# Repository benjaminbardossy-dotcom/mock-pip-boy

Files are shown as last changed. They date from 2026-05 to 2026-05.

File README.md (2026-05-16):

# Overview
The wrist boy is a wrist mounted device containing modules which allow it to take in readings such as the outside temperature, humidity, air pressure, air quality, user heart rate / SpO2 of the user. Readings will be displayed onto a 2.42in I2C OLED, which the player can interact with using the buttons attached. Other features include:\
-2 pairs of LED's acting as straight or perpendicular flashlights\
-A laser pointer(toggled through switches)\
-Vl53l0X module which can measure distance\
-A laser pointer for better accuracy when measuring distance\
-A small speaker + mic\
+Many other software features\
For a more indepth look at the features, see [Features](#features)\
**This design is still a WIP, and many other features are planned. See [The Future of The Wrist Boy](#the-future-of-the-wrist-boy)

# Why I Made This
I was inspired to make this after coming across this project: [The Chip-Boy](https://github.com/hungggryvic/Chip-Boy). Seeing this project, I was inspired to make my own with similar modules.

Despite similar ideas, I had envisioned a few changes to the design, including adding more "survival" based modules. I wanted this device to warn the user if there was any potential danger. To implement this, I added an SpO2 module to measure the users heartrate, an AHT20+BMP280 module for temp and air pressure, an MQ135 module for air quality, and a red LED which would flash if there was any potential danger to the user(E.x. low air quality readings from the MQ135, high temp readings from the AHT20+BMP280.).

However, the idea behind the wrist boy was always the same. I wanted a device able to take in readings from the environment around me, anytime, anywhere, with versatile highly modifiable modules which could easily be coded to fit any need. I wanted a device which could connect to wifi if needed, but run completely off grid whenever necessary as long as it has charge.

After taking into consideration what I wanted from this device, I've created the design below:

# The Design(WIP):

## Features
- **Main Functionality**
   - Custom PCB powered by an ESP32 module which serves as the heart of the device as it handles all firmware
   - Responsive user interface, which is displayed on an 2.42 inch OLED screen, and can be interacted with through the attached switches
   - Rechargeable LIPO battery which can be charged through the attached TP4056 module.
   - laser which toggles on for accurate measurement when using the VL53L0X, or can alternatively be toggled through the second switch attached
   - 2 pairs of LED's which function as flashlights for the user, and are toggled through the attached switches
   - Micro SD card reader module which function as extended storage for the ESP32. For this device it stores music data, which can then be played on the attached speaker.
- **Environmental Data Gathering**
   - MAX30102 module to measure the users heatrate
   - MQ135 module to measure general air quality
   - AHT20+BMP280 to measure environmental temperature and air pressure
   - VL53L0X module for accurately measuring distance to the nearest mm
- **Audio**
   - Small speaker to play music or other audio
   - Small microphone which takes in audio and can be used to program a variety of features, such as voice activated commands
   - A piezo buzzer which adds depth to the interface by playing different frequency beeps depending on user input

## The Case
\
I designed a case to mount the PCB to, which could then slip onto the user's wrist. The case features two separate pieces which snap together to ease 3D printing and reduce support generation where possible. The PCB itself mounts to the case through the use of M2 screws. The case features 4 small holes in each corner to place M2 heat inserts into, which then mount the PCB in place by screwing in 4 M2 screws into the 4 corners of the PCB. The case includes a small rectangular hole near the bottom, which the SpO2 module slots into, before the wires are strung through the hollow case and connected to the PCB. This allows proper heart rate readings to be read, as the module is lightly pressed into the user's wrist at constant pressure. The case also includes holes for both the MQ135 and AHT20+BMP280, allowing the sensors to fit into the case and under the PCB.

## The PCB
\
The PCB features a 2 layer design, with a track size of 0.25mm, and an overall sizing of 67x107mm. The microcontroller used was the ESP32. which is soldered directly to the board. The OLED screen is quite large, sitting at 48x70mm, and for this reason it is mounted to female headers, allowing it to sit overtop of the ESP32 and other components. The two pairs of LED's sit off the board, acting as flashlights.
## 3D View:
\

## Wiring Schematic

This wiring schematic is identical to the routing on the PCB, but shown in greater detail.

# Assembling Your Own
If you're interested in creating your own wrist boy, the simplified construction of the wrist boy is as follows:
1. Gather the necessary files(All files / folders referenced can be found at the top of this repo):
   - Download the step files found in folder labeled CAD Models
   - Download the zip file containing the gerber files for the PCB labeled wrist_boy_gerber.zip, found in the folder labeled PCB
2. Gather the Parts
   - See the BOM below and order any parts you don't already have using the links provided
   - Go to JLCPCB and start a new order
   - Drag and drop wrist_boy_gerber.zip into the file uploader
   - Submit the order
   - Upload the step files to a 3D printing application of your choice and print the models OR upload the step files to JLCPCB's 3D printing service and add to your existing PCB order if you don't have access to a 3D printer
3. Assemble
   - Solder components to the board following the rules below and using the schematic as reference
      - make sure to solder a 4 pin female header instead of the screen to the designated OLED pins on the board
      - Do not solder the aht20+bmp280, MQ135, laser pointer, or MAX30102 directly to the board
   - Place the MAX30102 into its designated slot near the bottom of the case, placing the wires through the case
   - Superglue the connecting pieces of the 3D printed case together and let set
   - Place the MQ135 and aht20+bmp280 into their places in the case, securing with M2 screws and nuts
   - Optionally mount the laser pointer to the top of the VL53l0X
   - Use the solder gun to melt the M2 heat inserts into the case in the holes located at each corner of the case
   - Place battery into the case and secure with double sided tape
   - Place the PCB on top of the case in line with the holes
   - Using M2 screws, secure the PCB to the case
4. Firmware
   - Download the code using the provided ino file wristboy_untested.ino
   - Plug the ESP32 in, and connect to whatever device you're using to upload the code
   - Upload the code to the ESP32

## BOM
| Material | Quantity | Cost($CAD) | Link |
| --- | --- | --- | --- |
| M2 Screws | 10 | 0.21 | https://www.amazon.ca/780Pcs-Screws-Metric-Washers-Steel-Black/dp/B0D7QCS5FL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 |
| M2 Nuts | 6 | 0.12 | https://www.amazon.ca/780Pcs-Screws-Metric-Washers-Steel-Black/dp/B0D7QCS5FL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 |
| M2 Heat Inserts | 4 | 0.56 | https://www.amazon.ca/HANGLIFE-Heat-Set-Threaded-Components-Soldering/dp/B0D477R64K?th=1 |
| ESP32 | 1 | 10.99 | https://www.amazon.ca/ELEGOO-ESP-WROOM-32-Development-Bluetooth-Microcontroller/dp/B0D8T7Z1P5?th=1 |
| Mini Step-Up Boost Converter | 1 | 3.66 | https://www.amazon.ca/CANADUINO%C2%AE-DC-DC-Step-Up-Converter-2-5-5V/dp/B09TZSGHYK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 |
| 3.7V 18650A 2000mAh LIPO Battery | 1 | 8.63 | https://www.aliexpress.com/item/1005010527559361.html?spm=a2g0o.order_list.order_list_main.5.46711802fXqOzT |
| 5 Way Switch | 1 | 0.88 | https://www.aliexpress.com/item/4000681560472.html?spm=a2g0o.order_list.order_list_main.44.46711802fXqOzT |
| Mini Laser Pointer | 1 | 0.66 | https://www.aliexpress.com/item/1005009410058180.html?spm=a2g0o.order_list.order_list_main.50.46711802fXqOzT |
| 2.42 inch OLED Display  | 1 | 13.58  | https://www.aliexpress.com/item/4000002579405.html?spm=a2g0o.order_list.order_list_main.61.46711802fXqOzT |
| TP4056 Lithium Battery Charger Module | 1 | 0.47 | https://www.aliexpress.com/item/32930640893.html?spm=a2g0o.order_list.order_list_main.71.46711802fXqOzT |
| VL53L0X Module | 1 | 5.69 | https://www.aliexpress.com/item/1005008798415699.html?spm=a2g0o.order_list.order_list_main.191.49da1802f3M5CC |
| MAX30102 Module | 1 | 3.07 | https://www.aliexpress.com/item/1005007015407514.html?spm=a2g0o.order_list.order_list_main.56.64ef1802V6ZYNr |
| MQ135 Module | 1 | 5.09 | https://www.aliexpress.com/item/1005009467470672.html?spm=a2g0o.order_list.order_list_main.91.46711802fXqOzT |
| AHT20+BMP280 Module | 1 | 4.89 | https://www.aliexpress.com/item/1005005982427374.html?spm=a2g0o.order_list.order_list_main.96.46711802fXqOzT |
| Mini Slide Switch 3pin | 3 | 0.37 | https://www.aliexpress.com/item/1005005633418066.html?spm=a2g0o.order_list.order_list_main.171.46711802fXqOzT |
| Micro Push Button | 2 | 0.10 | https://www.aliexpress.com/item/32815969627.html?spm=a2g0o.order_list.order_list_main.196.46711802fXqOzT |
| Led Diode, 3mm 5mm | 5 | 0.35 | https://www.aliexpress.com/item/1005007214694188.html?spm=a2g0o.order_list.order_list_main.226.46711802fXqOzT |
| Resistors | 10 | 0.06 | https://www.aliexpress.com/item/1005005855324735.html?spm=a2g0o.order_list.order_list_main.241.46711802fXqOzT |
| INMP441 Module | 1 | 5.89 | https://www.aliexpress.com/item/1005011560363321.html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 |
| Micro SD Card Module | 1 | 3.71 | https://www.aliexpress.com/item/1005010519562186.html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 |
| MAX98357A Module | 1 | 3.07  | https://www.aliexpress.com/item/1005007068815767.html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 |
| 8Ohm 1W Speaker | 1 | 4.82 | https://www.aliexpress.com/item/1005011920753806.html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 |
| Piezo Buzzer | 1 | 0.27 | https://www.aliexpress.com/item/1005006260328559.html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 |

# The Future of The Wrist Boy
This design is not final, and I plan on refining the PCB and case alot more in the future. I plan on having a fully integrated circuit with no prebuilt modules, which woiuld save space and allow me to build a full case which encloses the hardware, and I also plan on changing and refining the code as I test the hardware. Another large modification I have planned is the addition of a 5V solar panel to charge the battery, attached to a custom PCB which allows both USB-C charging and solar charging.

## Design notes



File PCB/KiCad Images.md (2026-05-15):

**KiCad schematic as an image:**

\
**KiCad pcb as an image**


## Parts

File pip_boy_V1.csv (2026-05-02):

Reference | Qty | Value | DNP | Exclude from BOM | Exclude from Board | Footprint | Datasheet | "Link"
BZ1 | 1 | Buzzer |  |  |  | custom_footprints:Piezo_buzzer_D10mm | ~ | "https://www.aliexpress.com/item/1005006260328559.html?curPageLogUid=fZmKYKihIY1A"
D1,D2,D3,D4,D5 | 5 | LED |  |  |  | Connector_PinSocket_2.54mm:PinSocket_2x01_P2.54mm_Vertical | ~ | "https://www.aliexpress.com/item/1005007214694188.html"
L1 | 1 | LASER |  |  |  | TestPoint:TestPoint_2Pads_Pitch5.08mm_Drill1.3mm | ~ | "https://www.aliexpress.com/item/1005009410058180.html"
R1,R2,R3,R4,R5,R6 | 6 | 10 |  |  |  | custom_footprints:Resistor_THT_L5.00mm_D1.0mm | ~ | "https://www.aliexpress.com/item/1005005855324735.html"
R7,R8 | 2 | 100K |  |  |  | custom_footprints:Resistor_THT_L5.00mm_D1.0mm | ~ | "https://www.aliexpress.com/item/1005005855324735.html"
R9 | 1 | 180 |  |  |  | custom_footprints:Resistor_THT_L5.00mm_D1.0mm | ~ | "https://www.aliexpress.com/item/1005005855324735.html"
S1 | 1 | Speaker |  |  |  | TestPoint:TestPoint_2Pads_Pitch5.08mm_Drill1.3mm | ~ | "https://www.aliexpress.com/item/1005011920753806.html?mp=1"
SW1,SW2,SW3 | 3 | SW_SPDT |  |  |  | Connector_PinSocket_2.54mm:PinSocket_1x03_P2.54mm_Vertical | ~ | "https://www.aliexpress.com/item/1005005633418066.html"
SW4,SW5 | 2 | SW_Push |  |  |  | Button_Switch_THT:SW_PUSH_6mm_H4.3mm | ~ | "https://www.aliexpress.com/item/32815969627.html"
U1 | 1 | ESP32 |  |  |  | custom_footprints:ESP32_elegoo |  | "https://www.amazon.ca/ELEGOO-ESP-WROOM-32-Development-Bluetooth-Microcontroller/dp/B0D8T7Z1P5?th=1"
U2 | 1 | VL53L0X |  |  |  | Connector_PinSocket_2.54mm:PinSocket_1x06_P2.54mm_Vertical |  | "https://www.aliexpress.com/item/1005008798415699.html"
U3 | 1 | SSD1309 |  |  |  | Connector_PinSocket_2.54mm:PinSocket_1x04_P2.54mm_Vertical |  | "https://www.aliexpress.com/item/4000002579405.html"
U4 | 1 | MAX30102 |  |  |  | Connector_PinSocket_2.54mm:PinSocket_2x04_P2.54mm_Vertical |  | "https://www.aliexpress.com/item/1005007015407514.html"
U5 | 1 | AHT20+BMP280 |  |  |  | Connector_PinSocket_2.54mm:PinSocket_1x04_P2.54mm_Vertical |  | "https://www.aliexpress.com/item/1005005982427374.html"
U6 | 1 | 5 way switch |  |  |  | custom_footprints:5_way_switch |  | "https://www.aliexpress.com/item/4000681560472.html"
U7 | 1 | MQ135 |  |  |  | Connector_PinSocket_2.54mm:PinSocket_1x04_P2.54mm_Vertical |  | "https://www.aliexpress.com/item/1005009467470672.html"
U8 | 1 | INMP441 |  |  |  | custom_footprints:INMP441 |  | "https://www.aliexpress.com/item/1005011560363321.html?mp=1"
U9 | 1 | SD Reader |  |  |  | custom_footprints:micro_SD_card_module |  | "https://www.aliexpress.com/item/1005010519562186.html?mp=1"
U10 | 1 | MAX98357A |  |  |  | custom_footprints:MAX98357A |  | "https://www.aliexpress.com/item/1005007068815767.html?mp=1"
U11 | 1 | Battery in |  |  |  | TestPoint:TestPoint_2Pads_Pitch5.08mm_Drill1.3mm |  | "NA"
U12 | 1 | TP4056 |  |  |  | custom_footprints:TP4056_module |  | "https://www.aliexpress.com/item/32930640893.html"
U13 | 1 | Boost Converter |  |  |  | custom_footprints:lM2596_module | "" | "https://www.amazon.ca/CANADUINO%C2%AE-DC-DC-Step-Up-Converter-2-5-5V/dp/B09TZSGHYK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"

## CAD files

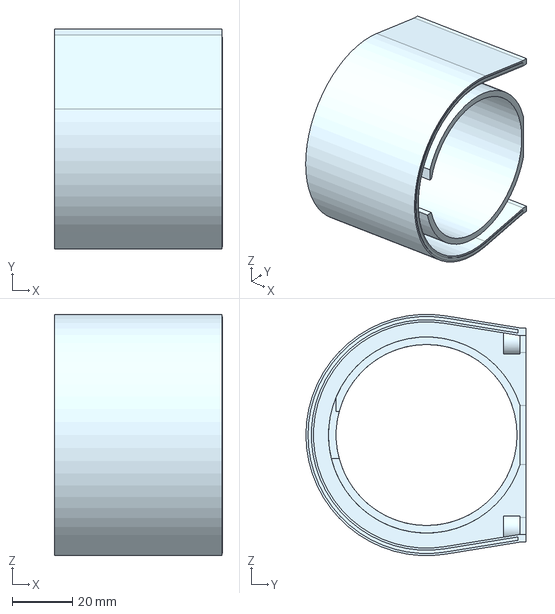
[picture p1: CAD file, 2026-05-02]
CAD Models/Wrist_base_left.step
55.8 x 73.0 x 79.9 mm

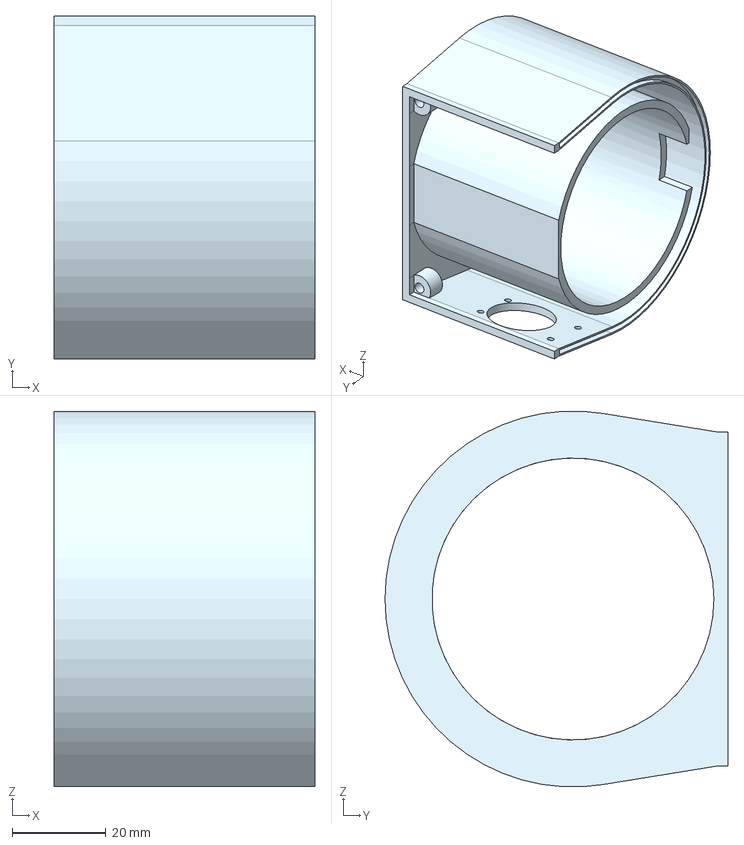
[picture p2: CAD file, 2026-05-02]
CAD Models/Wrist_base_right.step
55.5 x 73.0 x 79.9 mm

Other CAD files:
Fusion 360 Source File/wrist_boy_V1.f3z

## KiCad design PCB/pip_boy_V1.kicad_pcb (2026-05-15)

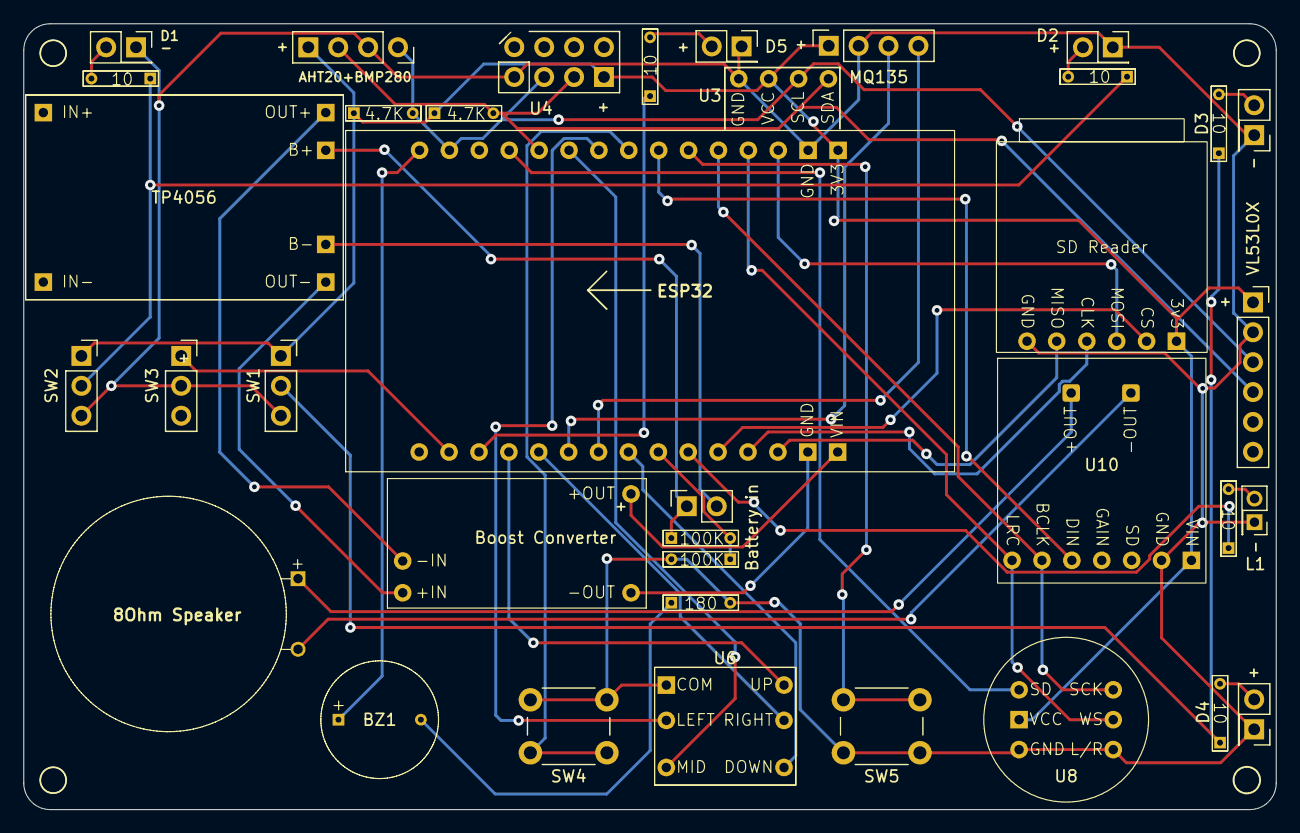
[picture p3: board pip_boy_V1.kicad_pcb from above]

Board: 4 copper layers, 106.4 x 66.8 mm, 37 parts (0 on the bottom side), 43 nets.

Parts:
BZ1: Buzzer; Piezo_buzzer_D10mm
Battery in: Battery in; PinSocket_1x02_P2.54mm_Vertical
D1, D2, D3, D4, D5: LED; PinSocket_2x01_P2.54mm_Vertical
L1: LASER; PinSocket_2x01_P2.00mm_Vertical
MQ135: MQ135; PinSocket_1x04_P2.54mm_Vertical
R1, R2, R3, R4, R5, R6: 10; Resistor_THT_L5.00mm_D1.0mm
R7, R8: 100K; Resistor_THT_L5.00mm_D1.0mm
R9: 180; Resistor_THT_L5.00mm_D1.0mm
R10, R11: 4.7K; Resistor_THT_L5.00mm_D1.0mm
S1: Speaker; 8Ohm_1W_20mm_speaker
SD Reader: SD Reader; micro_SD_card_module
SW1, SW2, SW3: SW_SPDT; PinSocket_1x03_P2.54mm_Vertical
SW4, SW5: SW_Push; SW_PUSH_6mm_H4.3mm
U1: ESP32; ESP32_elegoo
U3: SSD1309; SSD1309(4_pin)
U4: MAX30102; PinSocket_2x04_P2.54mm_Vertical
U5: AHT20+BMP280; PinSocket_1x04_P2.54mm_Vertical
U6: 5 way switch; 5_way_switch
U8: INMP441
U10: MAX98357A
U12: TP4056; TP4056_module
U13: Boost Converter; mini_step-up_boost_converter
VL53L0X: VL53L0X; PinSocket_1x06_P2.54mm_Vertical

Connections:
+3.3V: MQ135.1 (VIN), R10.1, R11.1, SD Reader.1 (VIN), SW1.1 (A), SW2.1 (A), U1.2 (3V3), U3.1 (VIN), U4.1 (VIN), U5.1 (VIN), U8.1 (VIN), U10.1 (VIN), VL53L0X.1 (VIN)
AO1: MQ135.4 (AO), U1.9 (GPIO33)
B1: U1.6 (GPIO34), U6.4 (UP)
B2: U1.7 (GPIO35), U6.5 (RIGHT)
B3: U1.10 (GPIO25), U6.6 (DOWN)
B4: U1.30 (GPIO18), U6.2 (LEFT)
B5: U1.31 (GPIO19), U6.3 (MID)
B6: SW5.1, U1.27 (GPIO16)
B7: SW4.1, U1.29 (GPIO5)
Battery_in: Battery in.1 (+Out), R8.1, U12.5 (B+)
DO1: MQ135.3 (DO), U1.8 (GPIO32)
GND: D1.1 (K), D2.1 (K), D3.1 (K), D4.1 (K), D5.1 (K), L1.1 (K), MQ135.2 (GND), R7.2, R9.2, SD Reader.2 (GND), SW1.3 (C), SW2.3 (C), SW3.2 (B), SW4.2, SW5.2, U1.38 (GND), U3.2 (GND), U4.2 (GND), U5.2 (GND), U6.1 (COM), U8.2 (GND), U8.4 (L/R), U10.2 (GND), VL53L0X.2 (GND)
GPIO2: U1.24 (GPIO2), U8.5 (WS), U10.3 (LRC)
GPIO3: U1.34 (GPIO3), U8.3 (SD)
GPIO4: U1.26 (GPIO4), U8.6 (SCK), U10.4 (BCLK)
GPIO12: SD Reader.5 (CLK), U1.14 (GPIO12)
GPIO13: SD Reader.6 (MISO), U1.16 (GPIO13)
GPIO14: SD Reader.3 (CS), U1.13 (GPIO14)
GPIO15: SD Reader.4 (MOSI), U1.23 (GPIO15)
GPIO17: U1.28 (GPIO17), U10.5 (DIN)
GPIO23: BZ1.1 (+), U1.37 (GPIO23)
GPIO26: R7.1, R8.2, U1.11 (GPIO26)
GPIO27: R6.1, U1.12 (GPIO27)
GPIO36: SW3.1 (A), U1.4 (GPIO36)
GPIO39: R5.1, U1.5 (GPIO39)
unnamed: BZ1.2 (-), R9.1
unnamed: D1.2 (A), R2.2
unnamed: D2.2 (A), R1.2
unnamed: D3.2 (A), R3.2
unnamed: D4.2 (A), R4.2
unnamed: D5.2 (A), R5.2
unnamed: L1.2 (A), R6.2
unnamed: R3.1, R4.1, SW1.2 (B)
unnamed: R1.1, R2.1, SW2.2 (B)
unnamed: S1.1, U10.8 (+OUT)
unnamed: S1.2, U10.9 (-OUT)
unnamed: Battery in.2 (-Out), U12.6 (B-)
unnamed: U12.3 (+out), U13.1 (-IN)
unnamed: U12.4 (-out), U13.2 (+IN)
Power+: U1.0 (VIN), U13.3 (+OUT)
Power-: U1.1 (GND), U13.4 (-OUT)
SCL: R11.2, U1.36 (GPIO22), U3.3 (SCL), U4.4 (SCL), U5.4 (SCL), VL53L0X.3 (SCL)
SDA: R10.2, U1.33 (GPIO21), U3.4 (SDA), U4.3 (SDA), U5.3 (SDA), VL53L0X.4 (SDA)

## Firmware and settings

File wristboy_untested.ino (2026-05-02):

//This is the current code that the ESP32 runs in order for the main features to work.
//Many other minor features will be added in the future
//I used a bunch of adafruit or other libraries, listed below in the include statements

#include <Wire.h>
#include <SPI.h>
#include <Adafruit_GFX.h>

#include <Adafruit_SSD1306.h>

#include "Adafruit_VL53L0X.h"

#include "MAX30105.h"
#include "heartRate.h"

#include <Adafruit_AHTX0.h>
#include <Adafruit_BMP280.h>

#define SCREEN_WIDTH 128
#define SCREEN_HEIGHT 64

#define OLED_RESET -1
Adafruit_SSD1306 display(SCREEN_WIDTH, SCREEN_HEIGHT, &Wire, OLED_RESET);
Adafruit_VL53L0X lox = Adafruit_VL53L0X();

//Useful Funcs(https://learn.adafruit.com/adafruit-gfx-graphics-library/graphics-primitives):
//display.fillScreen(colour);

//display.drawPixel(width, height, colour);

//display.drawLine(x1, y1, x2, y2, colour);
//When horizontal or vertical
//display.drawFastVLine(uint16_t x0, uint16_t y0, uint16_t length, uint16_t color);
//display.drawFastHLine(uint8_t x0, uint8_t y0, uint8_t length, uint16_t color);

//display.drawRect(x0, y0, w, h, colour);
//display.fillRect(x0, y0, w, h, colour);

//display.drawCircle(x0, y0, r, colour);
//display.fillCircle(x0, y0, r, colour);

//display.drawRoundRect(x0, y0, w, h, radius, color);
//display.fillRoundRect(x0, y0, w, h, radius, color);

//display.drawTriangle(x0, y0, x1, y1, x2, y2, color);
//display.fillTriangle(x0, y0, x1, y1, x2, y2, color);

//display.drawChar(x, y, char c, color, bg, size);

//display.setCursor(x0, y0);
//display.setTextColor(color);
//display.setTextColor(color, backgroundcolor);
//display.setTextSize(size);
//display.setTextWrap(boolean w);

const int xMid = SCREEN_WIDTH/2;// horizontal midpoint
const int yMid = SCREEN_HEIGHT/2;// vertical midpoint

int smallTextSize = 1;
//END OF display DECLARATION

const int batteryPin = 26; //For measuring battery percent

const int switchPin = 36;
const int laserPin = 27;

const int buttonL = 18;
const int buttonR = 32;
const int buttonDown = 25;
const int buttonUp = 34;
const int buttonBack = 7;
const int buttonSelect = 19;

//Corresponding button values
int BL_val = 0;
int BR_val = 0;
int BD_val = 0;
int BU_val = 0;
int BB_val = 0;
int BS_val = 0;

int lastBL_val = 0;
int lastBR_val = 0;
int lastBD_val = 0;
int lastBU_val = 0;
int lastBB_val = 0;
int lastBS_val = 0;

//Millis values
unsigned long previousMillis_Anim = 0;

// for heart
MAX30105 particleSensor;

const byte RATE_SIZE = 4; //Increase this for more averaging. 4 is good.
byte rates[RATE_SIZE]; //Array of heart rates
byte rateSpot = 0;
long lastBeat = 0; //Time at which the last beat occurred

float beatsPerMinute;
int beatAvg;

//for MQ135
int AO = 33;
int DO = 32;

//for AHT20 + BMP280
Adafruit_AHTX0 aht;
Adafruit_BMP280 bmp;
Adafruit_Sensor *bmp_pressure = bmp.getPressureSensor();
Adafruit_Sensor *bmp_temp = bmp.getTemperatureSensor();

// for animations
bool animActive = false;
bool animInitialized = false;

String menuNames[6] = {"Settings", "Distance", "Air Quality", "Sensors", "Heart", "Screen Saver"};
int currentSelection = 0;

enum State {mainMenu = -1, settings = 0, distance = 1, airQuality = 2, sensors = 3, heart = 4, screenSaver = 5};
State currentState = mainMenu;

void setup() {
  Serial.begin(115200);

  pinMode(buttonDown, INPUT_PULLUP);
  pinMode(buttonUp, INPUT_PULLUP);
  pinMode(buttonBack, INPUT_PULLUP);
  pinMode(buttonSelect, INPUT_PULLUP);

  if (!lox.begin()) {
    Serial.println(F("Failed to boot VL53L0X"));
    while(1);
  }

  if (!display.begin(SSD1306_SWITCHCAPVCC, 0x3C)) {
    Serial.println(F("Failed to boot display"));
    while(1);
  }

  // Initialize sensor
  if (!particleSensor.begin(Wire, 0x3)) //Use default I2C port, 400kHz speed
  {
    Serial.println("MAX30105 was not found. Please check wiring/power. ");
    while (1);
  }
  particleSensor.setup(); //Configure sensor with default settings


  if (!aht.begin()) {
    Serial.println("Didn't find AHT20");
    while(1);
  }

  if(!bmp.begin()){
    Serial.println("Didn't find BMP280");
    while(1);
  }

  /* Default settings from datasheet. */
  bmp.setSampling(Adafruit_BMP280::MODE_NORMAL,     /* Operating Mode. */
                  Adafruit_BMP280::SAMPLING_X2,     /* Temp. oversampling */
                  Adafruit_BMP280::SAMPLING_X16,    /* Pressure oversampling */
                  Adafruit_BMP280::FILTER_X16,      /* Filtering. */
                  Adafruit_BMP280::STANDBY_MS_500); /* Standby time. */

  //bmp_temp->printSensorDetails();

  
  display.clearDisplay();
  display.setTextSize(1);
  display.setTextColor(SSD1306_WHITE);
  display.setCursor(0, 0);
  display.display();
}

void loop() {
  lastBD_val = BD_val;
  lastBU_val = BU_val;
  lastBB_val = BB_val;
  lastBS_val = BS_val;

  BD_val = digitalRead(buttonDown);
  BU_val = digitalRead(buttonUp);
  BB_val = digitalRead(buttonBack);
  BS_val = digitalRead(buttonSelect);

  if(currentState != distance){
    digitalWrite(laserPin, switchPin);
  }

  switch(currentState){
    case mainMenu: in_mainMenu();
      display.display();
      break;

    case settings: in_settings();
      display.display();
      break;

    case distance: in_distance();
      display.display();
      break;

    case airQuality: in_airQuality();
      display.display();
      break;

    case heart: in_heart();
      display.display();
      break;

    case sensors: in_sensors();
      display.display();
      break;

    case screenSaver: in_screenSaver();
      //No display since handling it is more complex in animations;
      break;
  }
}

void in_mainMenu(){ //Main menu for scrolling through the other menu options

  if(BU_val == 0 && lastBU_val == 1 && currentSelection < (sizeof(menuNames) / sizeof(menuNames[0])) - 1){
    currentSelection++;
    display.clearDisplay(); //Reset oled screen
  }
  if(BD_val == 0 && lastBD_val == 1 && currentSelection > 0)
  {
    currentSelection--;
    display.clearDisplay(); //Reset oled screen
  }
  
  display.setCursor(5, yMid-(smallTextSize*2));
  display.print(currentSelection+1);
  display.print(". ");
  display.print(menuNames[currentSelection]);

  if(BS_val == 0 && lastBS_val == 1){
    currentState = static_cast<State>(currentSelection); //Convert the integer associated with currentSelection to the enum State through casting
    display.clearDisplay(); //Reset oled screen
  }
}

void in_settings(){ //In the future, allow the user to modify text colour, set wifi, and manage bluetooth
  display.setCursor(5, yMid-(smallTextSize*2));
  display.print("RV: ");
  display.print(analogRead(batteryPin)); //Output raw voltage

  checkReturn();
}

void in_distance(){ //Display distance readings from the VL53L0X **Add the ability to freeze measurements at the press of a button
  digitalWrite(laserPin, HIGH); //Turn laser on
  
  VL53L0X_RangingMeasurementData_t measure;

  lox.rangingTest(&measure, false); // pass in 'true' to get debug data printout

  if (measure.RangeStatus != 4) {  // phase failures have correct data
    display.setCursor(xMid-15, yMid-(smallTextSize*2));
    display.clearDisplay();
    display.print(measure.RangeMilliMeter);
    display.print("mm");
    display.display();
  } 
  else {
    display.setCursor(xMid-25, yMid-(smallTextSize*2)); // tweaked text position since the text is longer
    display.clearDisplay();
    display.print("Too Far!");
    display.display();
    //return;
  }

  checkReturn();
}

void in_airQuality(){ //Display air quality readings from the MQ135
  display.setCursor(5, yMid-(smallTextSize*2));
  display.println(analogRead(AO));
  display.println(analogRead(DO));

  checkReturn();
}

void in_sensors(){ //Display temperature, humidity, and air pressure readings from the AHT20+BMP280
  display.setCursor(5, yMid-(smallTextSize*2));
  sensors_event_t humidity, temp, temp_event, pressure_event;

  display.clearDisplay();
  aht.getEvent(&humidity, &temp); // populate temp and humidity objects with fresh data
  display.setCursor(0, 40);
  display.print("Temp: ");
  display.print(temp.temperature);
  display.println(" C");
  display.setCursor(0, 60);
  display.print("Hum: ");
  display.print(humidity.relative_humidity);
  display.println(" %");

  bmp_temp->getEvent(&temp_event);
  bmp_pressure->getEvent(&pressure_event);
  
  display.print(F("BMP 280 Temperature = "));
  display.print(temp_event.temperature);
  display.println(" *C");

  display.print(F("Pressure = "));
  display.print(pressure_event.pressure);
  display.println(" hPa");
  display.display();
  
  yield();

  checkReturn();
}

void in_heart(){ //Display heart rate, and blood O2 level if possible
  display.setCursor(5, yMid-10);
  long irValue = particleSensor.getIR();

  if (checkForBeat(irValue) == true)
  {
    //We sensed a beat!
    long delta = millis() - lastBeat;
    lastBeat = millis();

    beatsPerMinute = 60 / (delta / 1000.0);

    if (beatsPerMinute < 255 && beatsPerMinute > 20)
    {
      rates[rateSpot++] = (byte)beatsPerMinute; //Store this reading in the array
      rateSpot %= RATE_SIZE; //Wrap variable

      //Take average of readings
      beatAvg = 0;
      for (byte x = 0 ; x < RATE_SIZE ; x++)
        beatAvg += rates[x];
      beatAvg /= RATE_SIZE;
    }
  }

  display.clearDisplay();
  //display.print("IR=");
  //display.print(irValue);
  display.print("BPM=");
  display.println(beatsPerMinute);
  display.print(" Avg BPM=");
  display.println(beatAvg);

  if (irValue < 50000)    display.println(" No finger");
  display.display();

  checkReturn();
}

void in_screenSaver(){ //Display cool animations on the OLED
  playAnim(); // Seperate functions for different animations which the play can scroll through
  checkReturn();
}


struct Drop{
  int x;
  int y;
  int speed; //Added for varying speeds within animations
};

void playAnim(){
  const int numDrops = 60;
  Drop drops[numDrops];

  int delayLength = 20; //Make this variable alterable through the rotary encoder 

  bool shouldPlay = true;

  unsigned long currentMillis = millis();

  for (int k = 0; k < numDrops; k++) { //setup drops
    drops[k].x = random(0, SCREEN_WIDTH);
    drops[k].y = random(-60, 0);  // start somewhere offscreen for variety
    drops[k].speed = 2;
  }

  while (shouldPlay) {
    unsigned long currentMillis = millis();
    // Only update and redraw when delayLength ms have passed
    if (currentMillis - previousMillis_Anim >= delayLength) {
      previousMillis_Anim = currentMillis;

      display.clearDisplay();
      for (int k = 0; k < numDrops; k++) {
        checkReturn();
        display.drawPixel(drops[k].x, drops[k].y, 1);
        drops[k].y += drops[k].speed;           // move down
        if (drops[k].y >= SCREEN_HEIGHT) {      // reset when off‑screen
          drops[k].y = random(-30, 0);          // start somewhere offscreen for variety
          drops[k].x = random(0, SCREEN_WIDTH);
        }
      }
      display.display();
    }

    // Your other code (e.g. rotary encoder reading) can run here
    // without being blocked by delay():
    // checkRotaryEncoder(); // example
  }
}

void checkReturn(){ // function since this is called often
  if(BB_val == 0 && lastBB_val == 1){ //Return to main menu
    currentState = mainMenu;
    display.clearDisplay(); //Reset oled screen
  }
}

void setupDisplay(){

}

void beep(int pin, unsigned int frequency, unsigned long durationMs) { //Tone Without Hardware Timer
  unsigned long start = millis();
  unsigned long halfPeriodUs = 1000000UL / (frequency * 2);

  pinMode(pin, OUTPUT);

  while (millis() - start < durationMs) {
    digitalWrite(pin, HIGH);
    delayMicroseconds(halfPeriodUs);
    digitalWrite(pin, LOW);
    delayMicroseconds(halfPeriodUs);
  }

  digitalWrite(pin, LOW);
}

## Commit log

2026-04-16 Enhance README with detailed device description
    Updated project description to include device features and functionalities.
2026-04-19 Fix links in Parts_List.md
    Updated links for resistors and LEDs in the parts list.
2026-05-02 Add schematic image to KiCad_Schematic.md
2026-05-02 Add header for KiCad schematic image
2026-05-02 Add placeholder for Wrist_left CAD model
2026-05-02 Rename wristboy_KiCad.zip to PCB/Full Project Zip File
2026-05-02 Add KiCad PCB image to documentation
2026-05-02 Rename KiCad Images.md to PCB/KiCad Images.md
2026-05-02 Revise README with new project name and details
    Updated project name and expanded device features. Added photos and BOM with materials and links.
2026-05-02 Clean up BOM entries in pip_boy_V1.csv
    Removed old component data from the BOM.
    [pip_boy_V1.csv]
2026-05-02 Update laser component link in pip_boy_V1.csv
    [pip_boy_V1.csv]
2026-05-15 Update KiCad Images.md
2026-05-15 Rename wrist_boy_V1.f3z to Fusion 360 Source File/wrist_boy_V1.f3z
    [wrist_boy_V1.f3z]
